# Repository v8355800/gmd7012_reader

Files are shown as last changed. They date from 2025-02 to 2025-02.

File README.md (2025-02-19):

# Считыватель для накопителя "ГМД-7012" (далее `READER`) #

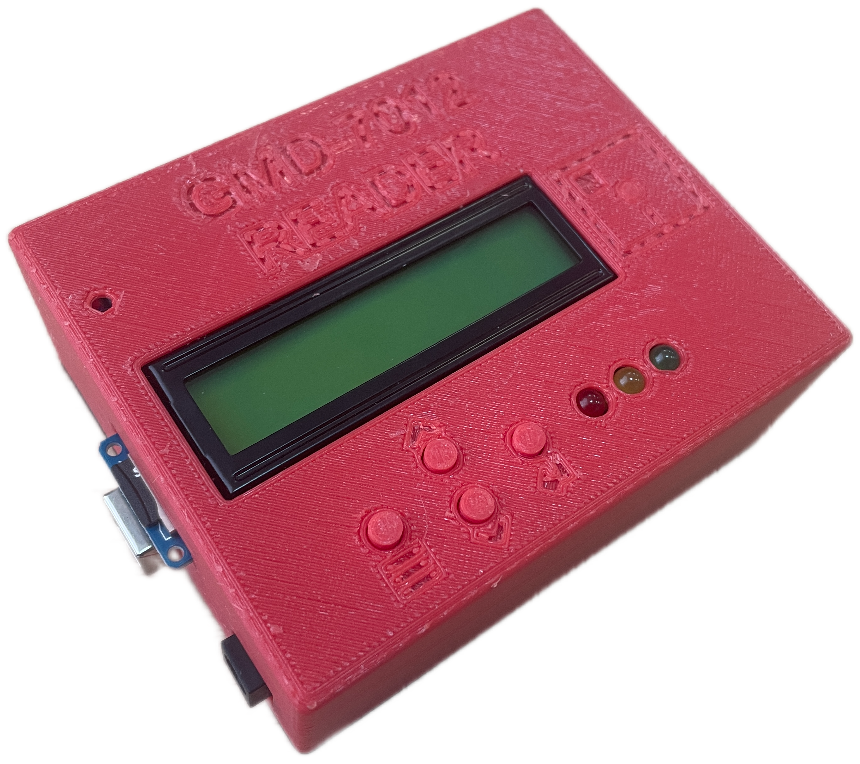
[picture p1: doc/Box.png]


## Описание ##

Устройство позволяет снимать образы 8-ми дюймовых дискет от накопителя "ГМД-7012" на MicroSD карту.  Представляет собой шилд (плату расширения) для Arduino Mega 2560 с кнопками, дисплеем и MicroSD адаптером.

## Сборка ##

Сборка устройства подробно описана в [ASSEMBLY.md](doc/ASSEMBLY.md) в папке *doc*.

## Питание устройства ##

* **USB Type-B**
Разъём USB Type-B предназначен для прошивки и питания платформы Arduino Mega 2560 по USB. Для коммуникации понадобится кабель USB Type-B.
* **DC Jack**
Коннектор DC Jack служит для подключения внешнего источника напряжения в диапазоне от 7 до 12 вольт. Например блок питания на 9В или 12В. Размер штекера 5.5*2.1 мм. Полярность: внутренний "+", внешний "-".  
Рекомендуется использовать блок питания 9В/2A.

Оба разъема расположены на левой стороне устройства.

## MicroSD карта ##

Поддерживаемый объем MicroSD: до 2 Гб  
Поддерживаемый объем MicroSDHC: до 32 Гб  
Карта должна иметь файловую систему FAT32.  

Опробовано с картой памяти MicroSDHC Class 10 объемом 8GB.

`Установка и извлечения карты памяти проводится только на отключенном от питания устройстве.`  
Если карта не установлена, то при подаче питания на устройство на дисплее будет отображаться *"SD CARD ERROR!"*.  
Если устройство зависает на экране вывода названия и версии ПО, попробуйте заново отформатировать карту.`

Разъем расположен с левой стороны устройства.

## Клавиши управления ##

На лицевой панели находятся 4 кнопки управления с помощью которых осуществляется навигация.  
* 1 = Меню  
* 2 = Вверх  
* 3 = Вниз  
* 4 = Enter

<!-- ## Индикация ##

"Красный" -   
"Желтый" -  
"Зеленый" - 
-->

## Использование ##

Для снятия образов дискет вам потребуется "НГМД-7012" и собственно сам `READER`. От того, в каком состоянии (насколько хорошо читает дискеты) находится "НГМД-7012" напрямую зависит качество создаваемых образов.

Процесс происходит следующим образом:
* Подключить кабель управления от "НГМД-7012" к `READER`;
* Установить MicroSD карту в слот, если она не установлена;
* Подать питание на `READER`;  
* Подать питание на накопитель "ГМД-7012";
* Дождаться отображения заставки с версией ПО, после чего прозвучит звуковой сигнал и на экране отобразиться меню;
* Вставить дискету в накопитель;
* С помощью клавиш "Вверх", "Вниз" выбрать нужный пункт "DUMP [0]" или "DUMP [1]" в зависимости от того с какого привода следует произвести считывание образа. [0] - левый ; [1] - правый
* Дождаться когда процесс завершиться. На экране появится надпись "DONE" и прозвучит звуковой сигнал. После нажатия любой кнопки появится начальное меню с выбором с какого привода снять образ.

## Экран процесса снятия дампа ##

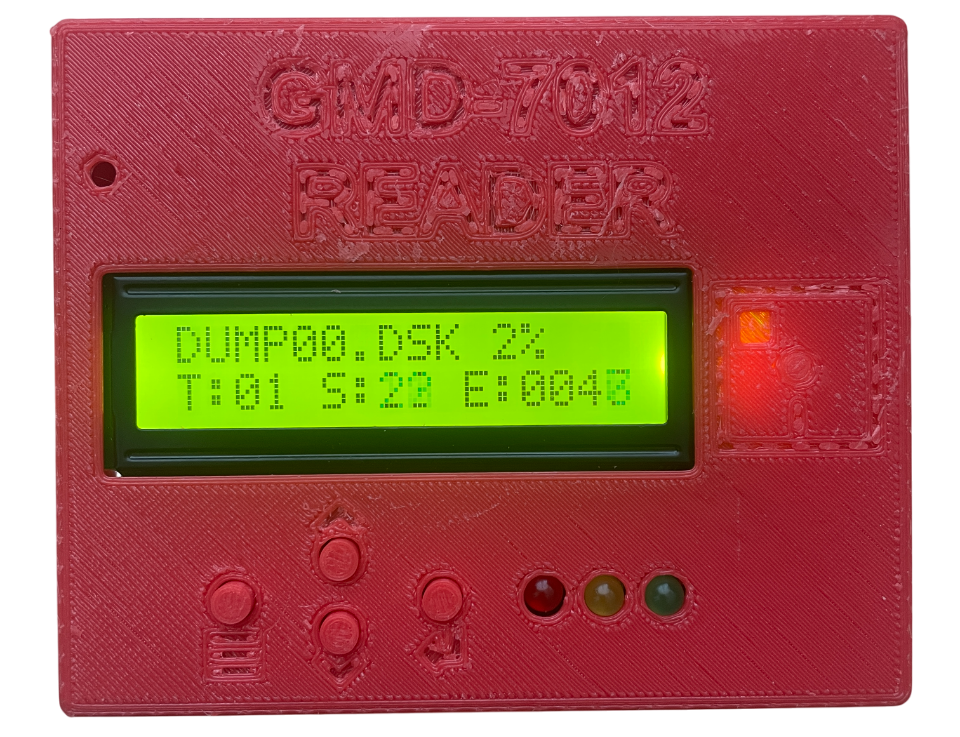
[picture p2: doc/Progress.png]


* *"DUMP00.DSK"* - Имя записываемого файла
* *"2%"* - Процент выполнения
* *"T:01"* - Текущая дорожка
* *"S:22"* - Текущий сектор
* *"E:043"* - Количество ошибок чтения

## Работа с образами дискет (дампами) ##

* Полученный образ можно скопировать на ПК используя кард-ридер. 
* Использовать в [Эмуляторе "НГМД-7012"](https://github.com/v8355800/rx02_emulator).

При создании дампа дискеты на флешке будет создан файл *DUMPXX.DSK (где XX - 00 до 99)*.Если во время считывания дискеты появлялись ошибки чтения секторов, то будет выполнено 5 попыток повторного чтения, если и после этого считать сектор не удалось, то в образ на место данного сектора будут записаны 00. В случае ошибок чтения помимо файла *DUMPXX.DSK* будет создан второй файл *DUMPXX.DSK_meta* в который будет помещен подробный лог по ошибкам чтения. Данный файл носит справочный характер, при переносе дампа на *ЭМУЛЯТОР* его копировать не нужно.

При хранение дампов на ПК их можно переименовывать как угодно, но при переносе на *ЭМУЛЯТОР* не стоит превышать 6 символов в имени, иначе на LCD дисплее они будут отображаться некорректно. Так что можно хранить на ПК под одним именем, а при переносе просто переименовывать копию.

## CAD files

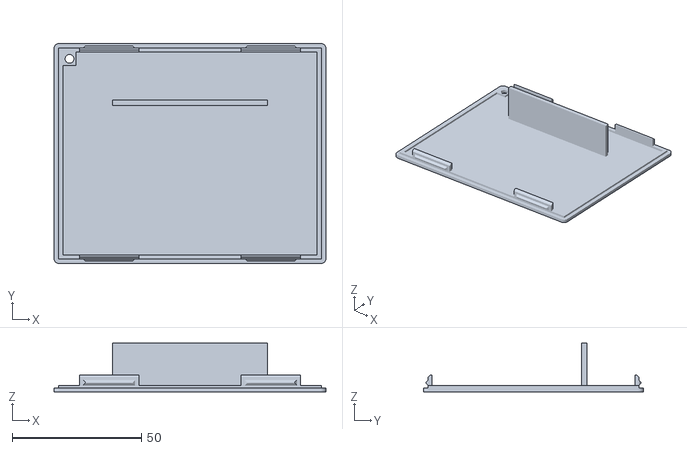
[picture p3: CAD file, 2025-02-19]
enclouse/Lid.stl
105.2 x 85.2 x 19.0

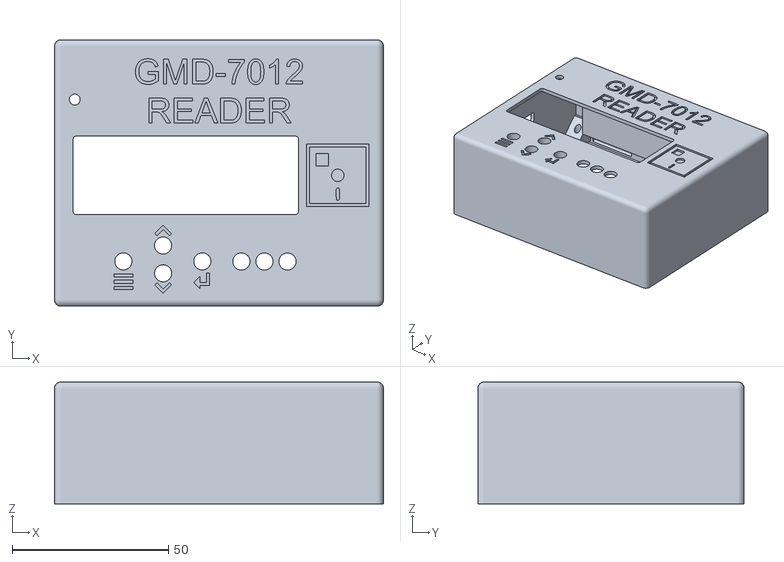
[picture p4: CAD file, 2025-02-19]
enclouse/Body.stl
105.2 x 85.2 x 39.0

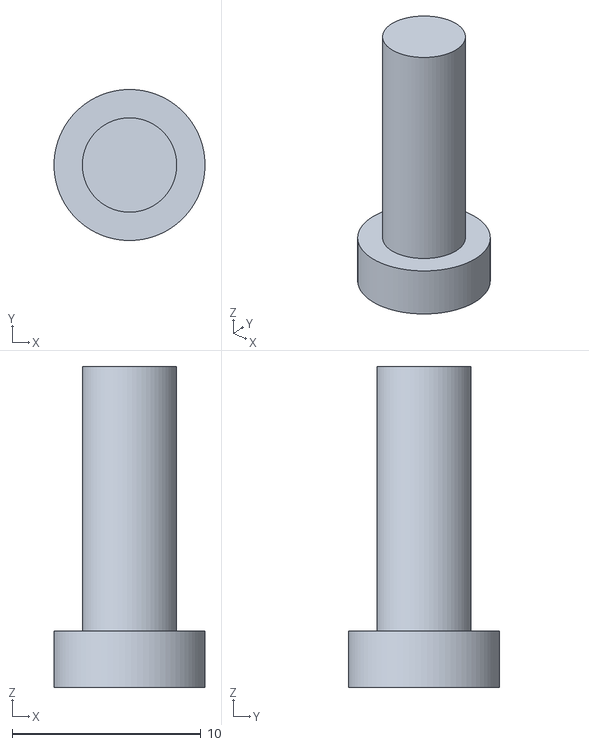
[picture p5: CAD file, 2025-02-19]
enclouse/Button.stl
8.00 x 8.00 x 17.0

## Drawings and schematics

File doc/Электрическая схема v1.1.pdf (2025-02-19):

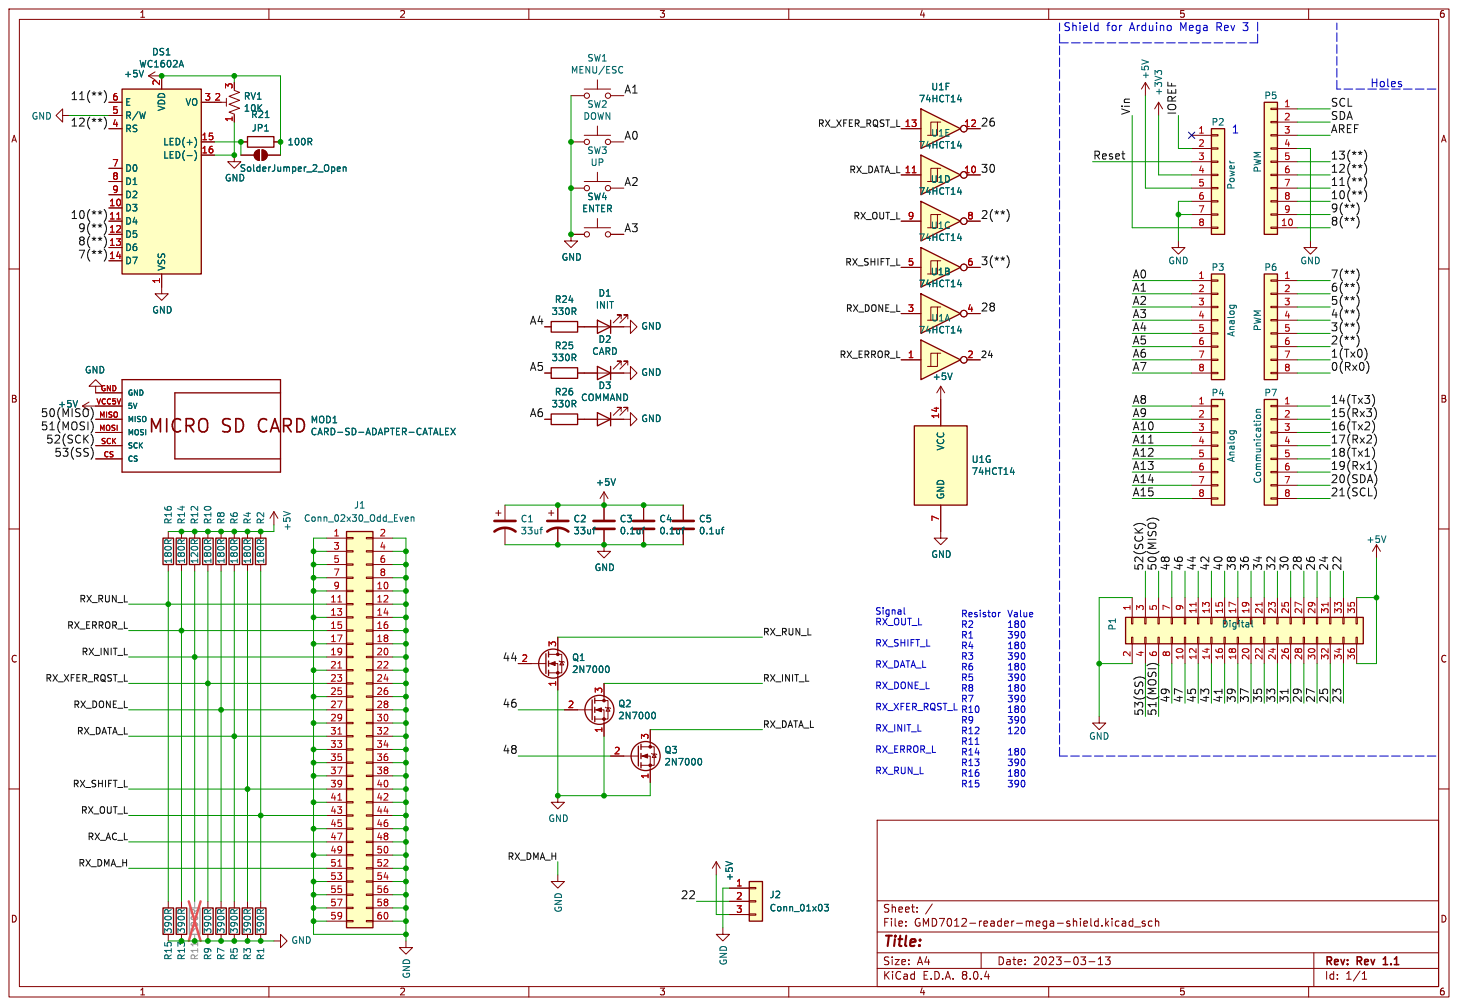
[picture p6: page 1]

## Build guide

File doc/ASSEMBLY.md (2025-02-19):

# Руководство по сборке считывателя для накопителя "ГМД-7012" (далее `READER`) #

## Сборка устройства

Для сборки устройства вам понадобиться:

1. Распаянная печатная плата устройства
2. Arduino Mega 2560 R3 (USB CH340)
3. Дисплей LCD 1602C без I2C
4. Адаптер для Micro SD Flash
5. Зуммер
6. MicroSD карта
7. Блок питания

## Где купить компоненты? ##

- Всю "рассыпуху" можно заказть в интернет-магазине ChipDip. Для удобства можно воспользоваться ссылкой на уже сформированную корзину. Количество компонентов расчитано на 10 печатных плат, если нужно меньше, то можно просто кратно уменьшить количество всех заказываемых позиций.  
[Корзина в ChipDip](https://www.chipdip.ru/cart/share/2VH5yriuXCz1h3LfwV9frz1fyJPbLA7jBDuQjtjyguGcRv8bEszTsHk1d4EooTHRyfYq3cdPZywZT95CQ4IUw855gfAyYqzsw3ijJ5LWnfdMUjMUVxApTBu0SUXfd2ztII).

- Arduino Mega 2560 R3 (USB CH340)  
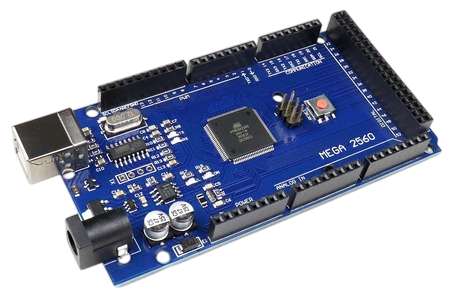
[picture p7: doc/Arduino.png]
    
  [Ozon](https://www.ozon.ru/search/?text=arduino+mega+2560+ch340)  
  [Wildberries](https://www.wildberries.ru/catalog/0/search.aspx?search=arduino+mega+2560+ch340)  

- LCD дисплей  
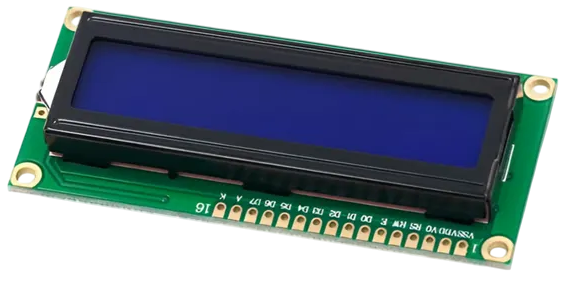
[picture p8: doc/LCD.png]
    
  [Ozon](https://www.ozon.ru/search/?text=LCD1602)  
  [Wildberries](https://www.wildberries.ru/catalog/0/search.aspx?search=LCD1602)  

- MicroSD адаптер  
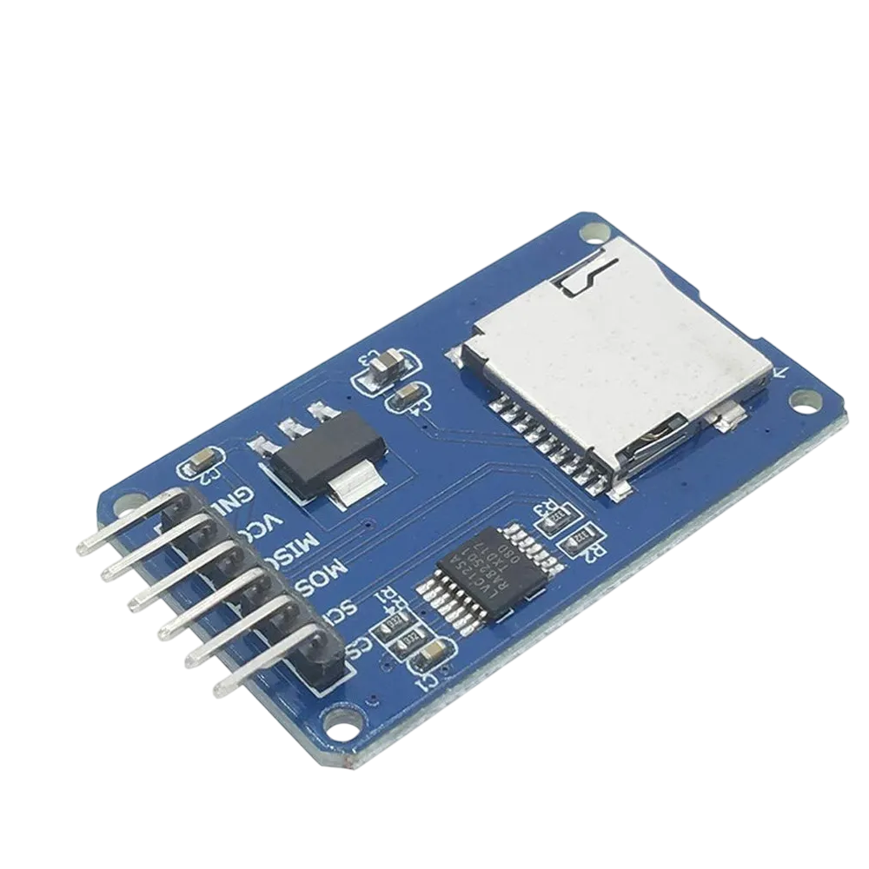
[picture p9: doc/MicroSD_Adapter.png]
    
  [Ozon](https://www.ozon.ru/search/?text=microsd+arduino)  
  [Wildberries](https://www.wildberries.ru/catalog/0/search.aspx?search=microsd+arduino)

- Зуммер  
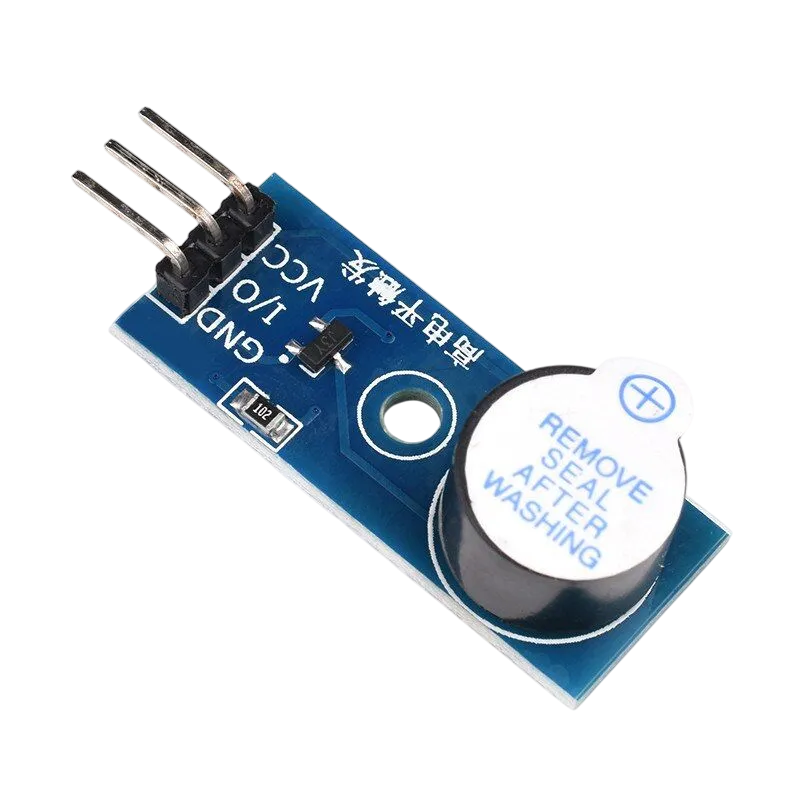
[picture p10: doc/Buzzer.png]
    
  [Ozon](https://www.ozon.ru/search/?text=модуль+зуммера)  
  [Wildberries](https://www.wildberries.ru/catalog/0/search.aspx?search=модуль+зуммера)

- MicroSD карта  
  [Ozon](https://www.ozon.ru/search/?text=microsd+8gb)  
  [Wildberries](https://www.wildberries.ru/catalog/0/search.aspx?search=microsd+8gb)

- Блок питания  
  [Ozon](https://www.ozon.ru/search/?text=блок+питания+9V)  
  [Wildberries](https://www.wildberries.ru/catalog/0/search.aspx?search=блок+питания+9V)

## Печатная плата ##

Вы можете скачать [Gerbers](../pcb/GMD7012-reader-mega-shield_for_NextPCB_v1.0.zip) и заказать изготовление плат на производстве (Резонит, JLCPCB, NextPCB ...). Это стандартная 2-ух слойная плата, медь 1oz (35 мкм),  размеры платы меньше 100mm x 100mm, что позволяет заказывать данные платы со значительной скидкой, т.к. многие фабрики предоставляют существенные скидки на изготовление печатных плат с такими параметрами. 

## Монтаж печатной платы ##

[Схема электрическая принципиальная](<Электрическая схема v1.1.pdf>)  
[Интерактивный список материалов (BOM)](bom/ibom.html)  

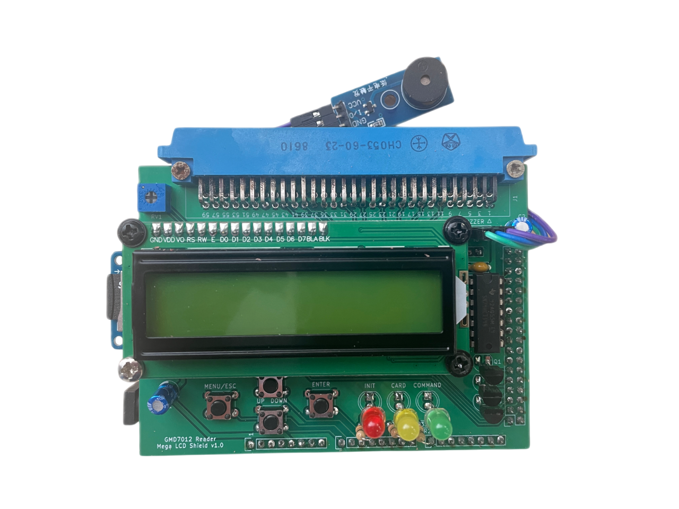
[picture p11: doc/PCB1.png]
PCB1

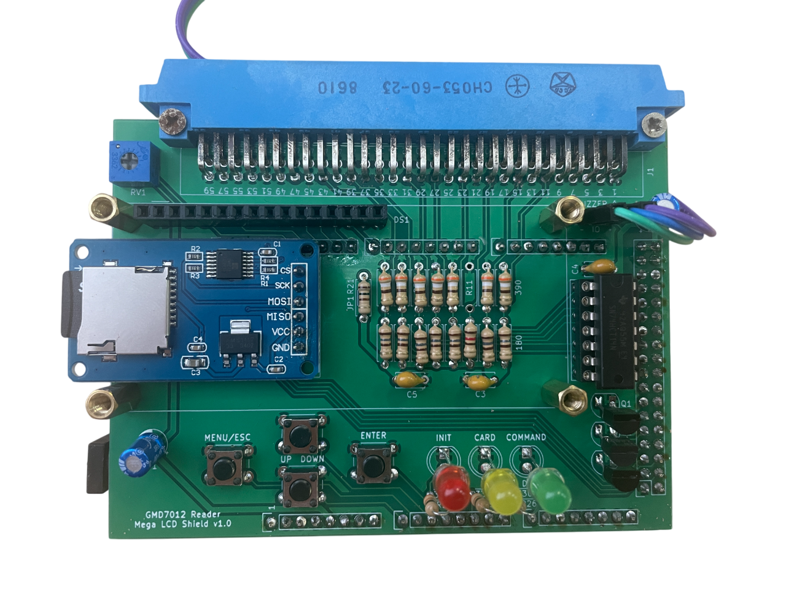
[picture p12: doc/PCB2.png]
PCB2


Плата предполагает выводной монтаж. Это сделано чтобы не предъявлять особых требований к умению человека, который будет запаивать компоненты на плату.

**Таблица установленных резисторов R1-R16**

| Сигнал | Резистор | Значение, Ом | Резистор | Значение, Ом |
| --- | --- | --- | --- | --- |
| RX_OUT_L | R2 | **180** | R1 | **390** |
| RX_SHIFT_L | R4 | **180** | R3 | **390** |
| RX_DATA_L | R6 | **180** | R5 | **390** |
| RX_DONE_L | R8 | **180** | R7 | **390** |
| RX_XFER_RQST_L | R10 | **180** | R9 | **390** |
| RX_INIT_L | R12 | **120** | R11 | - |
| RX_ERROR_L | R14 | **180** | R13 | **390** |
| RX_RUN_L | R16 | **180** | R15 | **390** |

На место перемычки *JP1 (R21)* запаивается резистор номиналом 100 Ом.

Светодиоды следует запаять так, чтобы остались длинные выводы, иначе при сборке в корпус они будут утоплены слишком глубоко.

Микросхема *U1* устанавливается на панель. Вместо микросхемы *U1 74HCT14*, может быть установлена 74AHCT14, 74HC14, 74AHC14. Микросхемы следующих серий лучше не устанавливать: 7414, 74LS14, 74ALS14, 74xx04.

## MicroSD, LCD и Buzzer ##

Для установки MicroSD адаптера потребуется выпаять родной коннектор установленный на плате, затем впаять вилку *PLS-6* в предусмотренное место на печатной плате и сверху запаять MicroSD адаптер. Следует соблюсти горизонтальность, иначе в последсвии будут проблемы по установке платы в корпус.

LCD дисплей устанавливается в 16-пиновый разъем *DS1* расположенный на печатной плате. По четырем сторонам устанавливаются стойки 11мм с разьбой М3 и фиксируется винтами.

Buzzer (динамик) подключается с помощью 3-х жильного провода мама-мама к разъему *J2*. Распиновка нанесена на шелкографии (левый - GND; центральный - IO; правый - +5V).

## Корпус ##

Можно распечатать на 3D-принтере. В папке [enclouse](../enclouse) находятся `STL` модели.
* Body - основная часть  
* Lid - нижняя крышка  
* Button - кнопки (4 шт. на один корпус)

Требуется установить поддержки в месте выреза под разъем подключения дисковода.

## Прошивка Arduino ##

- Установить [драйвер CH340](https://wch-ic.com/downloads/CH341SER_EXE.html)
- Подключить Arduino Mega 2560 к ПК
- Скачать утилиту для прошивки HEX файлов:
[xLoader](https://github.com/binaryupdates/xLoader/archive/refs/heads/master.zip)

1. Разархивировать скачанный архив на жесткий диск
2. Запустить *XLoader.exe*
2. Выбрать [HEX файл](<../binary/gmd_reader v1.0.hex>) с прошивкой
3. Выбрать *Device - Mega(ATMEGA2560)*
4. Выбрать *COM порт*
5. Установить *Baud rate - 115200*
6. Нажать кнопку Upload 

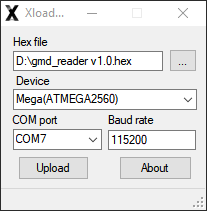
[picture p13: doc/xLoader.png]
xLoader


Если не получилось прошить, то рекомендуется ознакомится с материлами в интернете по [прошивке Arduino](https://www.google.com/search?q=прошивка+arduino+hex)

## Яркость LCD дисплея ##

После сборки устройства, при первом подключении, LCD экран будет светиться и ничего не отображать. С помощью отвертки, поворачивая подстроечный резистор *RV1*, необходимо добиться комфортного уровня яркости подсветки экрана.
